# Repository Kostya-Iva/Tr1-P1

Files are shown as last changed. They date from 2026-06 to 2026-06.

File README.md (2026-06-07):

# Tr1-P1
Cartesian parallel manipulator, featuring "Tripteron" with 3 DoF, made as a student project for particular universitu course.
* Image of a robot:

  <p align="center">
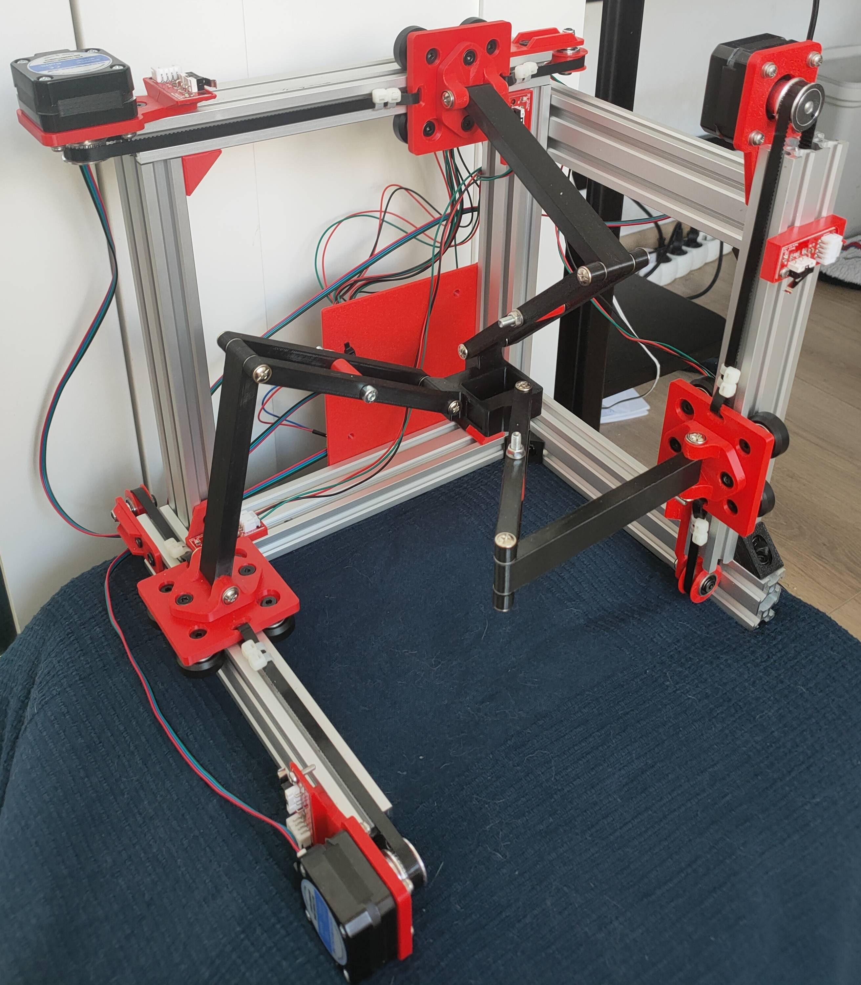
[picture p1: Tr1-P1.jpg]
Trippi
    
  </p>
# Motivation
The Tripteron project was born out of a practical need within the **EPIC** student research group: automating the preparation of metallographic specimens without breaking the bank.

Since professional, dedicated lab equipment is financially out of reach for most student budgets, this project delivers a cost-effective, simple to program, versatile alternative.

# Mechanical design

# Electronical design

# Programming
The system interfaces with three stepper motor drivers (X, Y, Z axes), dedicated limit switches (endstops) for homing, and control hardware.
The code architecture takes form of a state machine and it is described with this diagram:
  <p align="center">
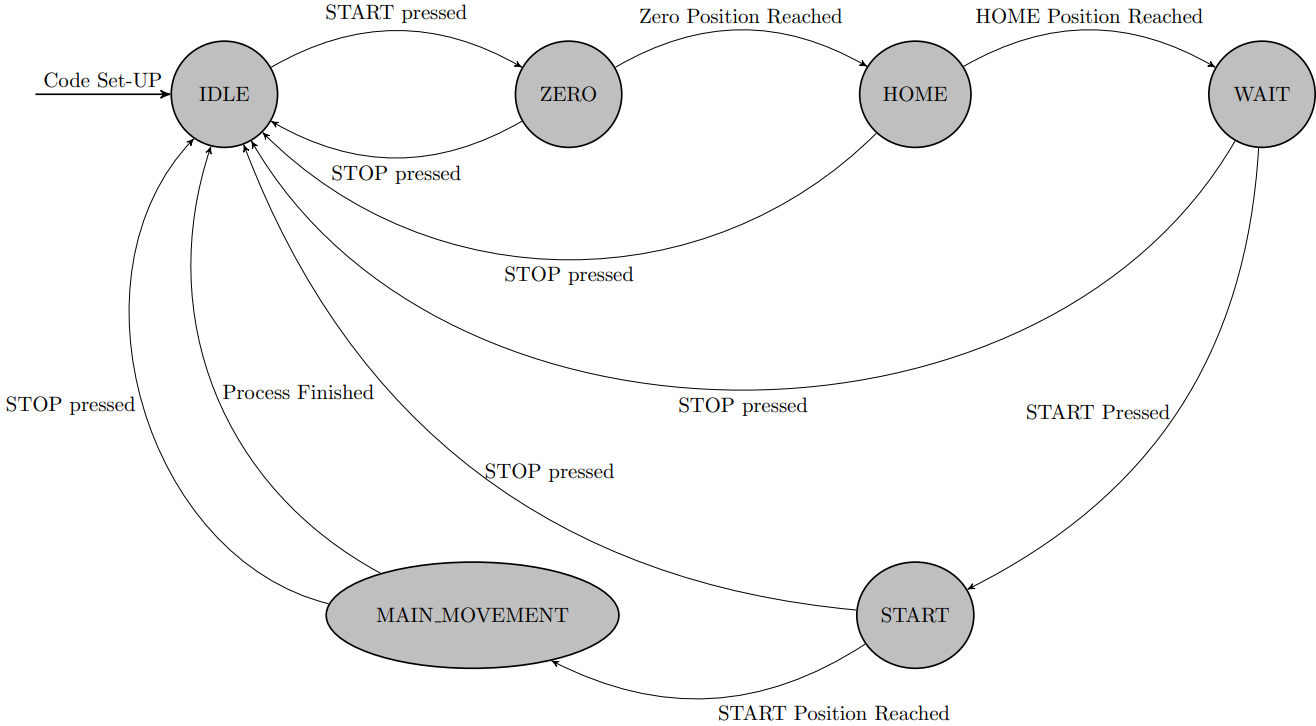
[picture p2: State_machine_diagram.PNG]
Stany
    
  </p>
  
Such architecture is described with one file, named: *stany.ino* written in the Arduino IDE for ESP32 DevBoard 

### Pin Mapping
| Component / Function | ESP32 Pin | Input / Output | Configuration / Description |
| :--- | :---: | :---: | :--- |
| **X-Axis STEP** | `GPIO22` | **OUTPUT** | Generates movement pulses for the X axis |
| **X-Axis DIR** | `GPIO23` | **OUTPUT** | Controls the direction of rotation for the X axis |
| **Y-Axis STEP** | `GPIO18` | **OUTPUT** | Generates movement pulses for the Y axis |
| **Y-Axis DIR** | `GPIO19` | **OUTPUT** | Controls the direction of rotation for the Y axis |
| **Z-Axis STEP** | `GPIO17` | **OUTPUT** | Generates movement pulses for the Z axis |
| **Z-Axis DIR** | `GPIO16` | **OUTPUT** | Controls the direction of rotation for the Z axis |
| **X-Axis Endstop** | `GPIO35` | **INPUT_PULLUP** | Limit switch for X home position |
| **Y-Axis Endstop** | `GPIO32` | **INPUT_PULLUP** | Limit switch for Y home position |
| **Z-Axis-bottom Endstop** | `GPIO33` | **INPUT_PULLUP** | Limit switch for Z home position |
| **Z-Axis-upper Endstop** | `GPIO25` | **INPUT_PULLUP** | Limit switch for Z home position |
| **START Button** | `GPIO14` | **INPUT_PULLUP** | Initiates the calibration and automation cycle |
| **STOP Button** | `GPIO12` | **INPUT_PULLUP** | Hardwired safety trigger for Emergency Stop |
---

#### State Descriptions:

* **`STATE_IDLE`** Remains stationary, actively polling the `START` button pin.
  
* **`STATE_HOMING`** Triggered after pressing START. Establishing the machine's absolute reference point.
  
* **`STATE_READY`** The homing was successfull. The parallel effector is calibrated at its home base, actively polling the `START` button pin.
  
* **`STATE_PROCESSING`** The system dynamically generates step pulses for all three axes simultaneously, executing predefined movement trajectory
  
* **`STATE_FINISHED`** The polishing cycle is complete. Retracts the effector away from the workpiece area, and transitions back to `STATE_IDLE` for the next run.

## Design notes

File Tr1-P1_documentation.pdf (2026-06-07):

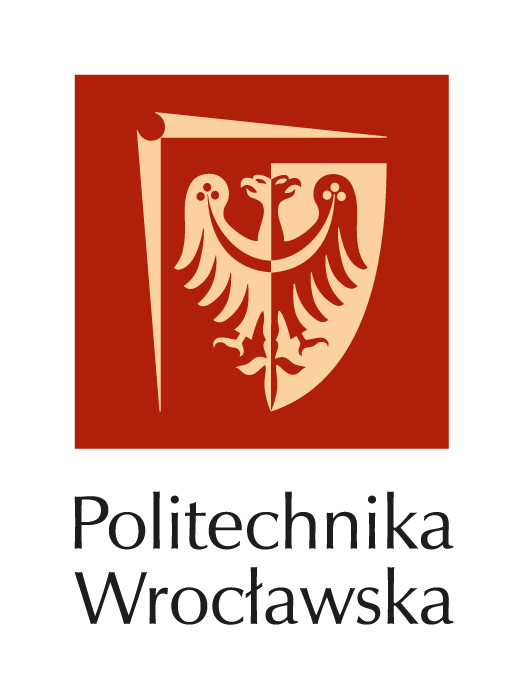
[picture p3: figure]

# Projekt Tripterona

## Bartłomiej Łuczeńczyk 277592 Mikołaj Mroczko 277576 Paweł Czerny 282945 Kostiantyn Ivanov 277567

Projekt Tripterona

## Spis treści

1 Koncept | 3
2 Wymagania | 4
3 Architektura | 5
4 Schemat blokowy architektury | 6
5 Mechanika | 7
6 Elektronika | 12
7 Oprogramowanie | 16
8 Załączniki | 23

## 1 Koncept

Projekt tripterona stanowi alternatywną formę konstrukcji mechanizmu równoległego, który zachowuje równoległość efektora względem płaszczyzny oraz umożliwia niezależny ruch w poszczególnych osiach. Konstrukcja została zaprojektowana z myślą o uniwersalności i łatwej adaptacji do różnych zadań realizowanych przez koło naukowe EPIC.

Platforma ta będzie wykorzystywana do automatyzacji procesu wykonywania zgładów metalograficznych. Ze względu na ograniczony budżet koła naukowego zakup profesjonalnych urządzeń oraz dedykowanych narzędzi nie jest możliwy, dlatego zaproponowane rozwiązanie alternatywne spotkało się z pozytywnym odbiorem zarządu koła.

Aby zminimalizować koszty produkcji urządzenia, podjęto decyzję o wykorzystaniu profili aluminiowych oraz elementów wytwarzanych metodą druku 3D, uzupełnionych o niezbędne komponenty elektroniczne, sensory i aktuatory.

Należy zaznaczyć, że przedstawiona konstrukcja stanowi jedynie prototyp urządzenia. Wersja końcowa może istotnie różnić się pod względem gabarytów, dokładności wykonania oraz zastosowanych materiałów.

Możliwy jest również dalszy rozwój projektu oraz opracowanie nowych, dedykowanych wersji urządzenia, dostosowanych do konkretnych zastosowań.

## 2 Wymagania

Wymagania interesariuszy

- Umożliwia precyzyjne pozycjonowanie efektora w przestrzeni roboczej,
- zapewnia ruch niezależny w trzech osiach (X, Y, Z),
- zachowuje równoległość efektora względem płaszczyzny roboczej,
- rozwiązanie niskokosztowe,
- łatwy w transporcie i adaptacji do różnych zastosowań,

Wymagania systemowe

- Układ ruchu oparty o mechanizm równoległy,
- odpowiedni obszar roboczy (architektura),
- umożliwia sterowanie poprzez mikrokontroler,
- umożliwia integrację odpowiednich końcówek roboczych.

Wymagania funkcjonalne

- przemieszczanie efektora w osiach X, Y, Z,
- utrzymywanie orientacji efektora,
- wykonywanie zaprogramowanej trajektorii ruchu,

Wymagania niefunkcjonalne

- wykorzystanie łatwo dostępnych komponentów,
- łatwość montażu i demontażu, powtarzalności działania urządzenia,
- możliwość przenoszenia urządzenia,

## 3 Architektura

Warstwa mechaniczna
- profile aluminiowe,
- elementy łączące (łączniki kątowe, łączniki systemowe),
- ramiona mechanizmu wykonane metodą druku 3D,
- wózki liniowe,
- prowadnice liniowe,
- platforma efektora,
- koła pasowe, napinacze, taśmy napędowe,
- mocowania silników, obudowy elementów.

Warstwa elektroniczna
- mikrokontroler ESP 32,
- płyta główna,
- sterownik silników krokowych,
- silniki krokowe NEMA 16,
- czujniki krańcowe,
- zasilacz,
- Przyciski start/stop.

Warstwa programowa

- sterowanie silnikami krokowymi,
- obsługa czujników krańcowych,
- procedura homing,
- kontrola trajektorii ruchu,

## 4 Schemat blokowy architektury

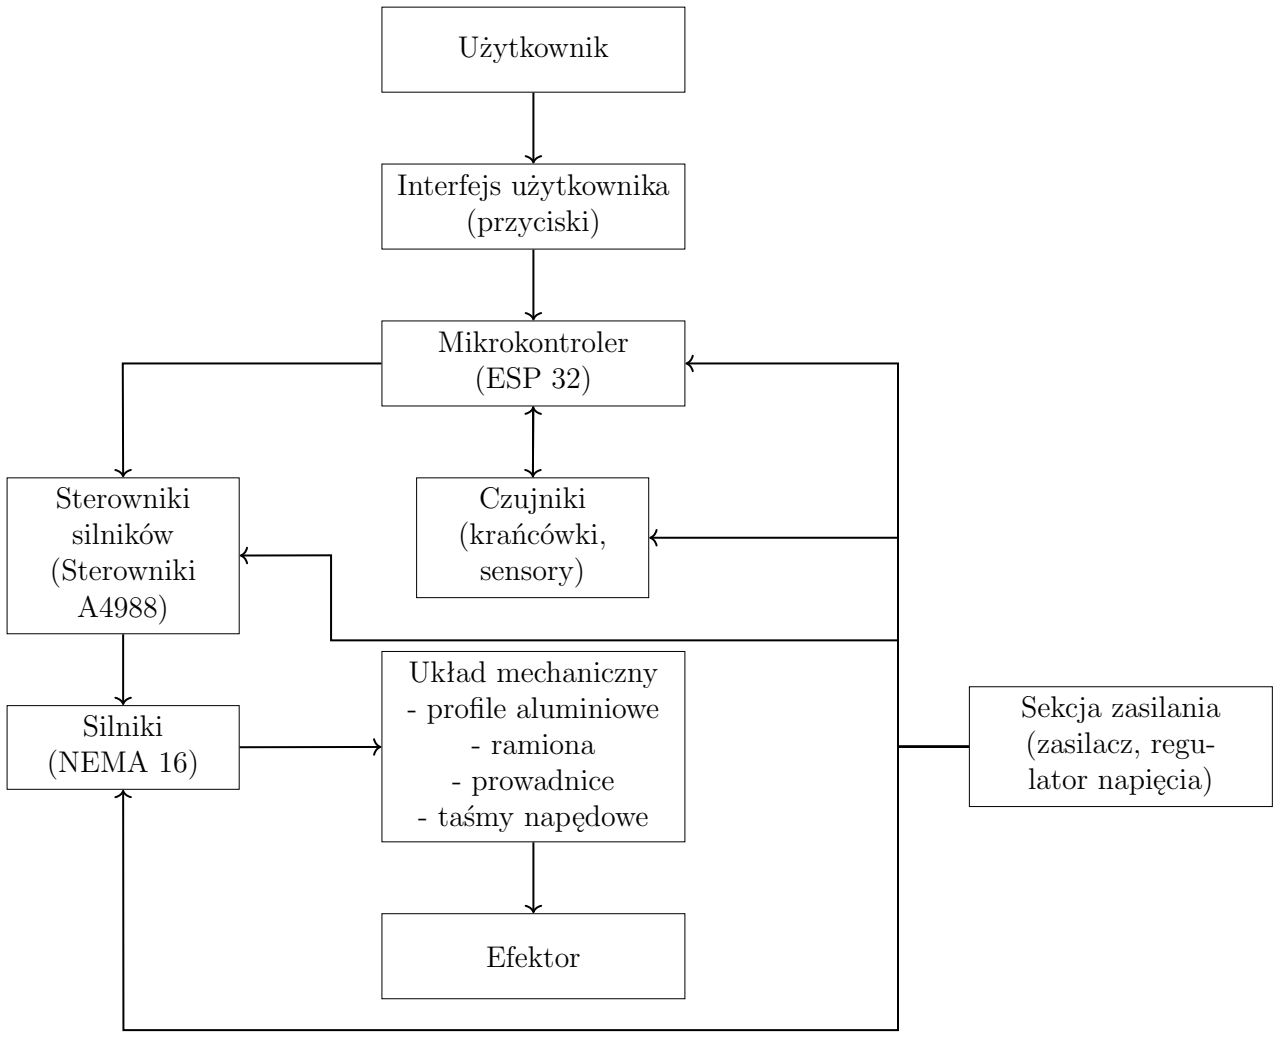
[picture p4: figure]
Użytkownik; Interfejs użytkownika (przyciski); Mikrokontroler (ESP 32); Sterowniki silników (Sterowniki A4988); Silniki (NEMA 16); Czujniki (krańcówki, sensory); Układ mechaniczny - profile aluminiowe - ramiona - prowadnice - taśmy napędowe; Efektor; Sekcja zasilania (zasilacz, regu- lator napięcia)

Rysunek 1: Schemat blokowy architektury systemu tripterona

## 5 Mechanika

### 5.1 Model 3D konstrukcji

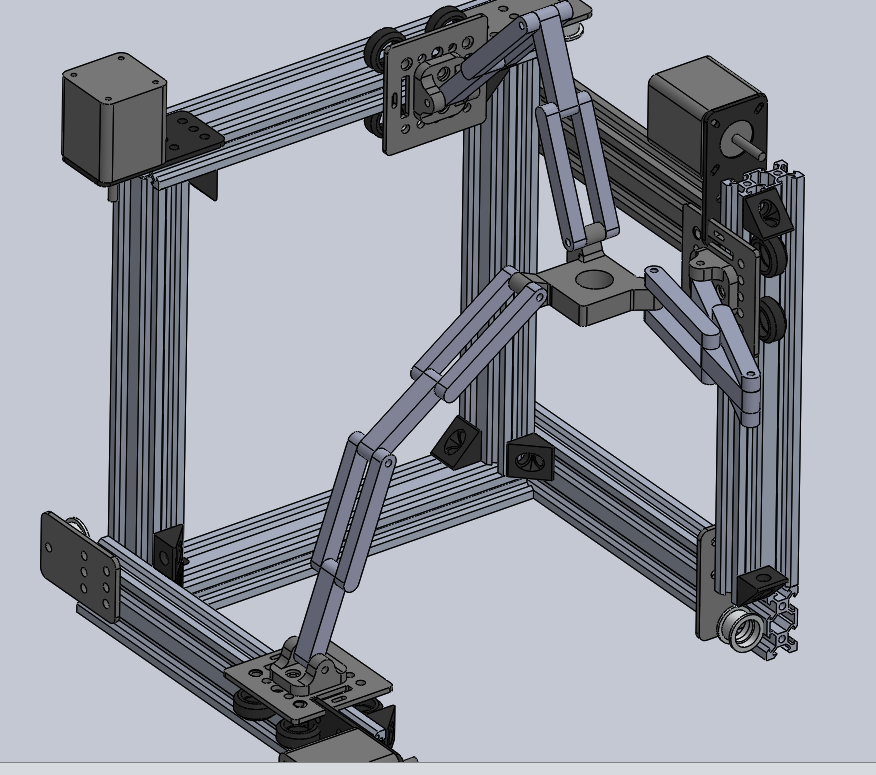
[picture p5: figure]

Rysunek 2: Render modelu 3D zaprojektowanego układu

Rysunek przedstawia finalną geometrię układu po etapach iteracji projektowej. Model stanowi podstawę do analizy mechanicznej i przeprowadzonych symulacji.

Konstrukcja wykonana została ze standardowych profili aluminiowych oraz elementów wykonanych w technice druku 3D. Zastosowanie profili aluminiowych typu V-Slot zapewnia odpowiednią sztywność całej struktury przy jednoczesnym zachowaniu stosunkowo niskiej masy układu oraz umożliwia prowadzenie wózków liniowych. Elementy wykonane w technologii druku 3D znacząco obniżają koszt wykonania oraz pozwalają na dostosowanie części do indywidualnych potrzeb konstrukcji, co umożliwiło szybkie iteracje projektowe oraz optymalizację kształtów pod kątem funkcjonalnym.

### 5.2 Pole robocze

Pole robocze zaprojektowanego układu zostało wyznaczone metodą eksperymentalną poprzez symulację ruchu końcówki efektora z wykorzystaniem przebiegów sinusoidalnych w osiach X, Y oraz Z. Takie podejście pozwoliło na odwzorowanie skrajnych położeń mechanizmu oraz określenie rzeczywistego zakresu pracy układu. Zaprojektowany system posiada pole robocze o wymiarach 12 × 12 × 12 cm, co zapewnia wystarczającą przestrzeń do realizacji zakładanych zadań oraz testów funkcjonalnych. Uzyskany zakres ruchu uwzględnia ograniczenia wynikające z geometrii ramion oraz długości elementów wykonawczych.

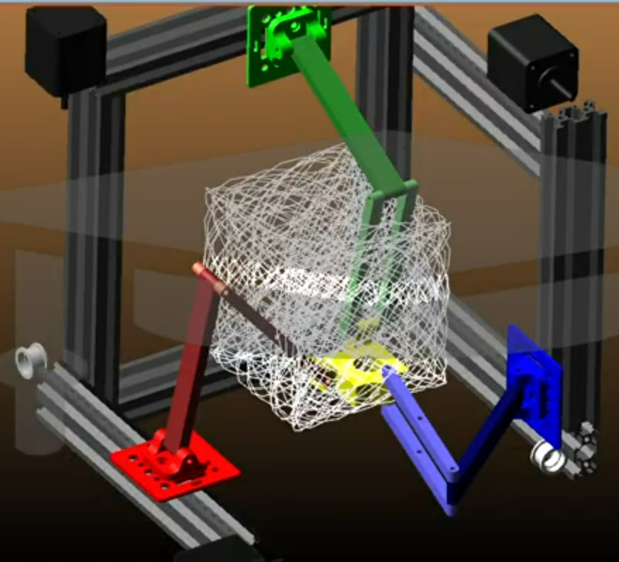
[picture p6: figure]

Rysunek 3: Wizualizacja pola roboczego flanszy efektora

Na rysunku przedstawiono wizualizację wyznaczonego pola roboczego wraz z zaznaczonym obszarem dostępnych pozycji efektora. W praktyce rzeczywisty obszar roboczy może nieznacznie odbiegać od wartości teoretycznych ze względu na luzy mechaniczne oraz elastyczność elementów konstrukcyjnych.

### 5.3 Symulacja

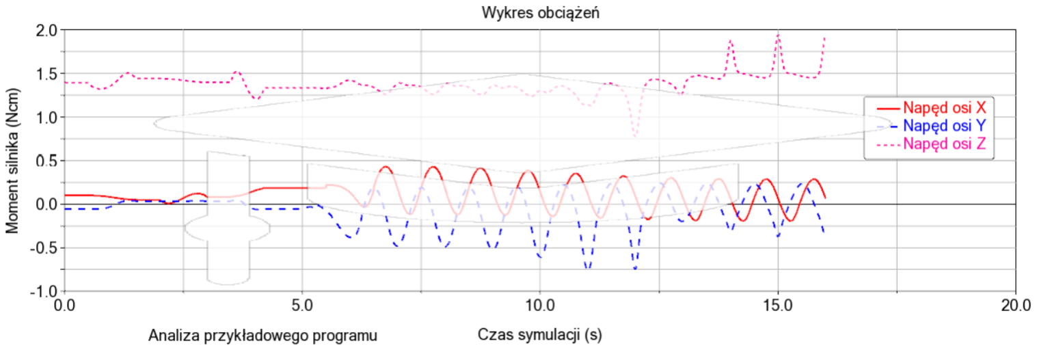
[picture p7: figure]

Rysunek 4: Zarejestrowane siły

Po zamodelowaniu mechanizmu przeprowadzono symulację ruchu w programie Adams w celu wyznaczenia sił działających w poszczególnych osiach układu. Wartości zarejestrowanych sił wynosiły maksymalnie:

- 0,5 Ncm dla osi X
- 0,6 Ncm dla osi Y
- 2,0 Ncm dla osi Z

Warto zaznaczyć, że uzyskane wartości sił mogą ulegać zmianie w zależności od zastosowanego narzędzia roboczego oraz przyjętej trajektorii ruchu manipulatora. Z tego względu przy doborze silników konieczne jest uwzględnienie odpowiedniego zapasu momentu obrotowego. Niewielkie wartości wyznaczonych obciążeń zapewniły jednak dużą swobodę w projektowaniu układu napędowego.

### 5.4 Problemy konstrukcyjne

Jednym z głównych wyzwań projektowych było opracowanie flanszy montażowej efektora. Konstrukcja musiała jednocześnie nie ograniczać pola roboczego urządzenia, zapewniać możliwość łatwego montażu różnych końcówek roboczych oraz umożliwiać integrację serwomechanizmów odpowiedzialnych za sterowanie efektorem. Wymagało to kilku iteracji projektowych.

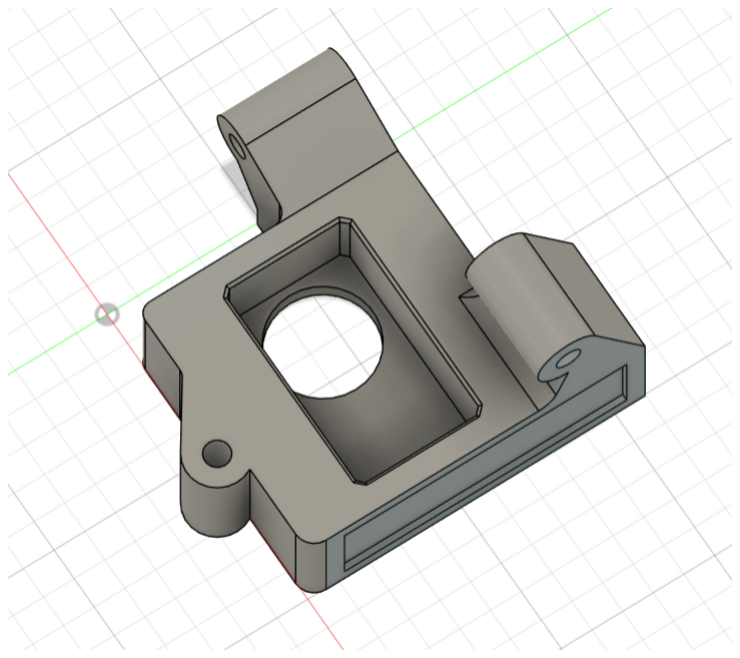
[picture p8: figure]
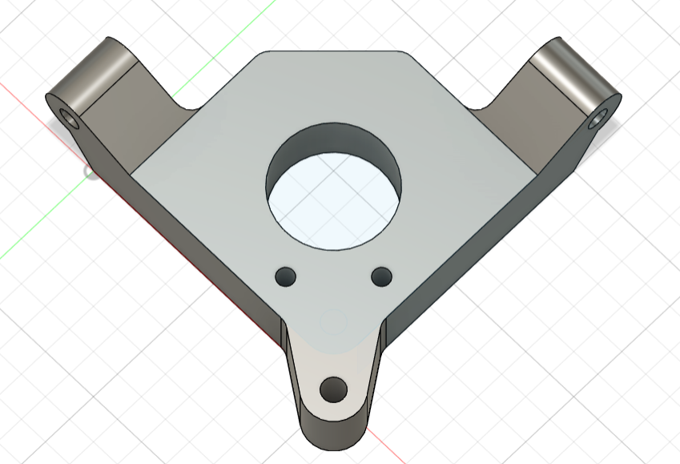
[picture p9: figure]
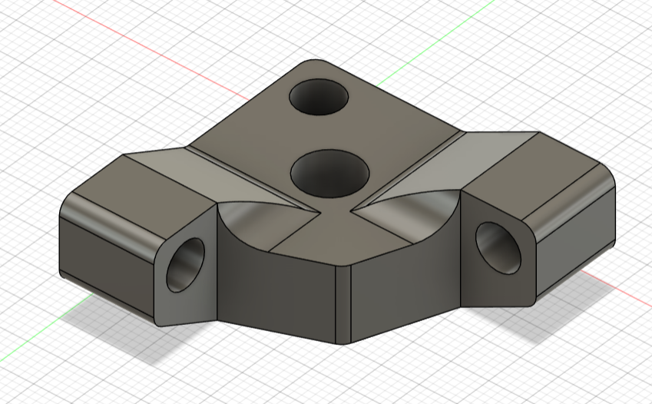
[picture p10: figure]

Rysunek 5: Kolejne wersje projektu flanszy efektora

Końcowa wersja pozwoliła uzyskać maksymalny obszar roboczy zostawiając pole na montaż zarówno efektorów jak i przykręcenie serwomechanizmów.
Kolejnym istotnym problemem projektowym była konstrukcja ramion robota. Głównym celem było zminimalizowanie masy całego układu przy jednoczesnym zachowaniu odpowiedniej sztywności konstrukcji. Dodatkowym wyzwaniem było takie zaprojektowanie geometrii ramion, aby uniknąć ich wzajemnego krzyżowania się w pełnym zakresie ruchu.

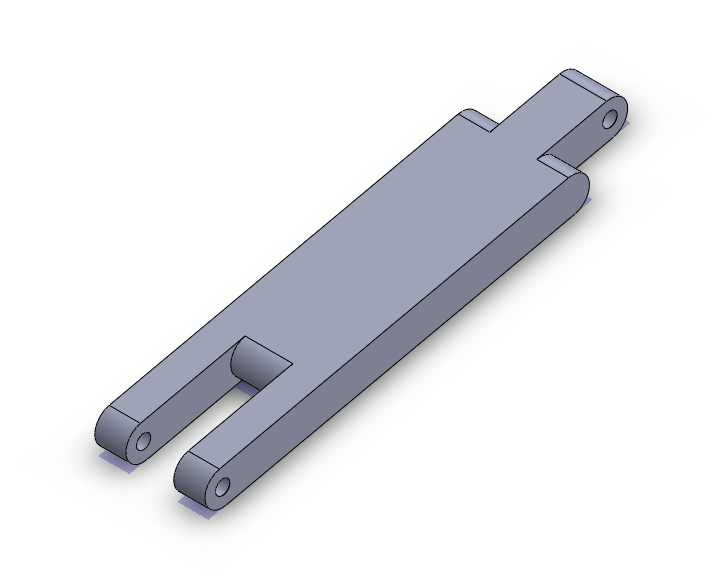
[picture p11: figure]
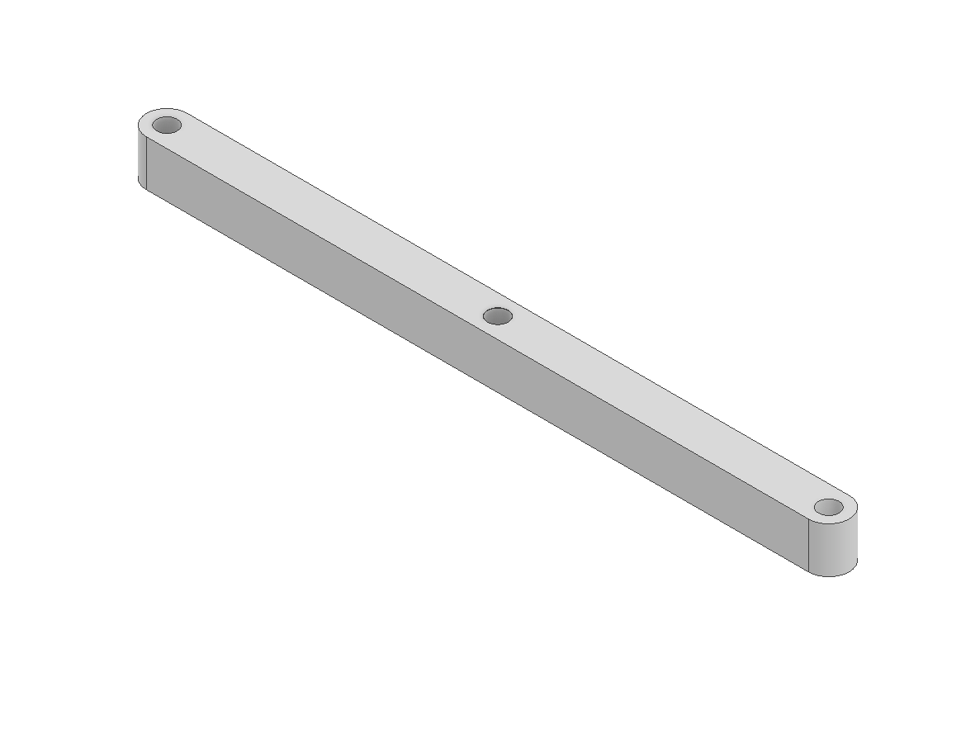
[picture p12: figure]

Rysunek 6: Kolejne wersje projektu ramion robota

### 5.5 Interfejs mechanika–elektronika

Na podstawie wykonanej konstrukcji oraz przeprowadzonych symulacji dobrano silniki napędowe typu Nema 16 Bipolar o momencie trzymającym 12 Ncm oraz kącie kroku 0,9°. Zastosowane silniki zapewniają odpowiedni zapas momentu względem obciążeń wynikających z masy elementów ruchomych oraz oporów mechanicznych układu. Wybór silników o mniejszym kącie kroku umożliwia realizację ruchów o wysokiej rozdzielczości, co bezpośrednio przekłada się na precyzję pozycjonowania osi roboczych.

Przyjęta konstrukcja mechaniczna pozwoliła również na określenie wymagań dla układu elektronicznego odpowiedzialnego za sterowanie ruchem. Liczba osi roboczych oraz zastosowane silniki krokowe determinują konieczność zastosowania wielokanałowego systemu sterowania umożliwiającego niezależną kontrolę każdej osi.

Ze względu na charakterystykę zastosowanych silników wymagane jest sterowanie mikrokrokowe, które zwiększa efektywną rozdzielczość ruchu oraz ogranicza drgania układu mechanicznego. Układ sterowania powinien zapewniać odpowiedni prąd fazowy, a także umożliwiać płynną regulację prędkości i przyspieszeń, co pozwala na uniknięcie gubienia kroków podczas pracy dynamicznej.

### 5.6 Spis elementów konstrukcyjnych

Lp. | Nazwa elementu | Kod / oznaczenie | Ilość
1 | Śruba Low Profile M5x25mm | M5x25mm | 12
2 | Śruba Low Profile M5x8mm | M5x8mm | 12
3 | Dystans aluminiowy 6mm | HW1018NC | 6
4 | Dystans aluminiowy 3mm | HW1016NC | 3
5 | Double T-NUT M5 | HW1029NC | 6
6 | T-nut | - | 3
7 | Zębatka GT2 (30 zębów, otw. Fi.5) | HW1036WC | 3
8 | Kółka (Xtreme Solid lub Solid) | HW1215WK / HW1212WK | 12
9 | Idler Pulley | HW1093WK | 3
10 | Napiacz | Druk własny | 3
11 | Podkładka do silnika (DYNAMIXEL) | Druk własny | 3
12 | Podkładka do silnika (NEMA) | Druk własny | 3
13 | Płyta V-SLOT Gantry Plate (Opcja 20mm) | Druk własny | 3
14 | Pasek GT2 5mm | HW1037GC | 3
15 | Profil V-SLOT 2040 | 2040-sr-mb | 8
16 | Silnik krokowy NEMA 16 Bipolar | 16HM12-0634D | 3
17 | Eccentric Spacer 6mm | HW1073NC | 6
18 | Zacisk do pasków zębatych | HW1024GC | 3
19 | Złącze meblowe śrubowe | - | 3
20 | Ramię | Druk własny | 3
21 | Przedramię | Druk własny | 6
22 | Kiść | Druk własny | 1
23 | Bark | Druk własny | 3
24 | Łączniki profili | Druk własny | 10

Tabela 1: Zestawienie elementów konstrukcyjnych

## 6 Elektronika

### 6.1 Schemat ideowy

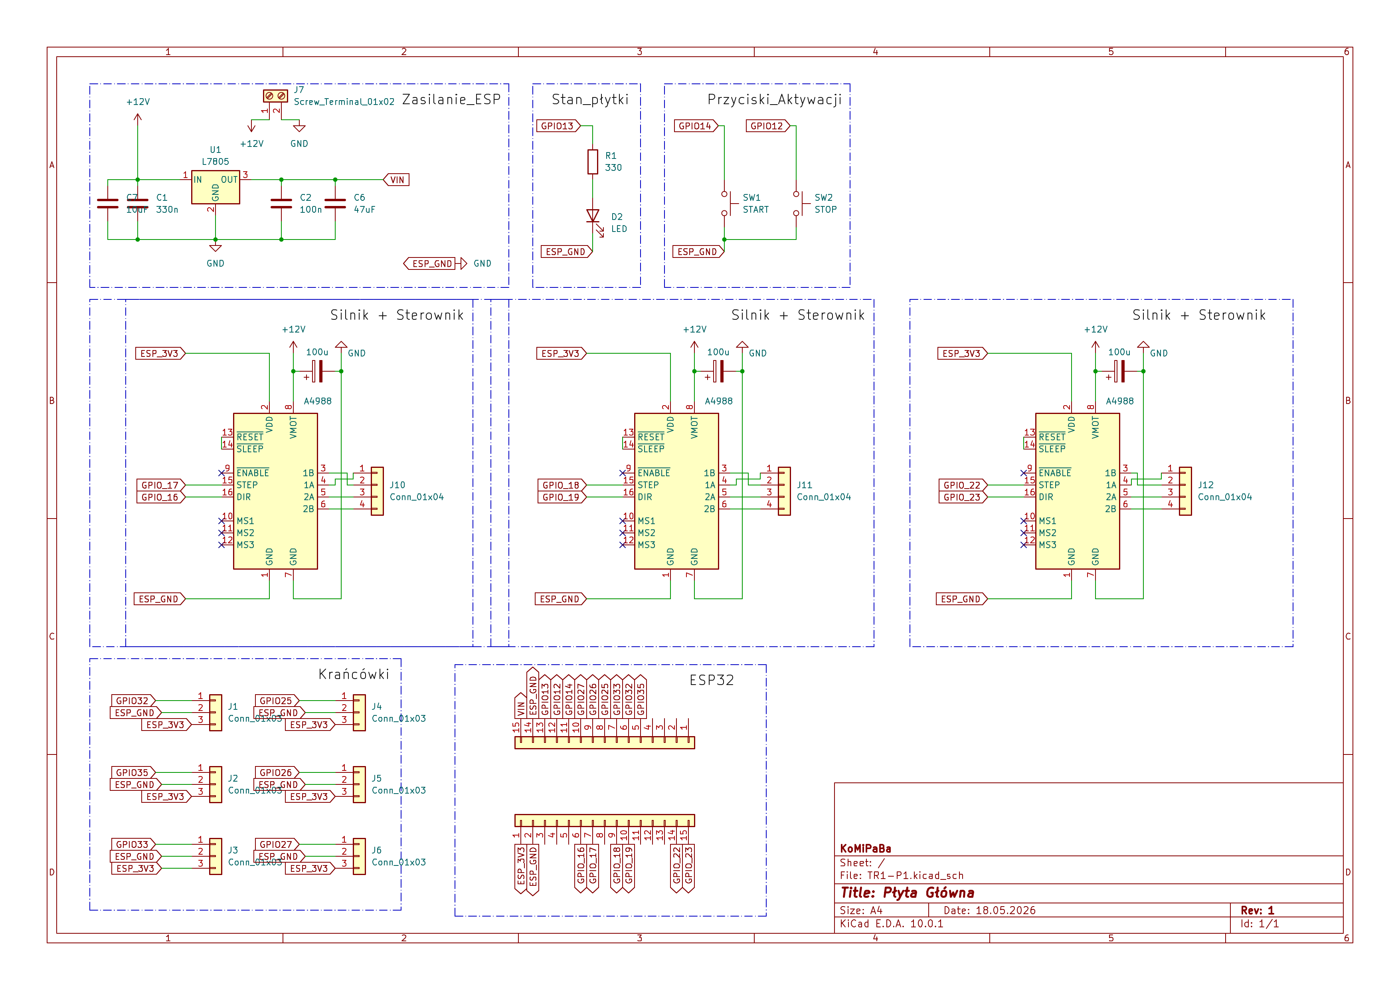
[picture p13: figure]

Rysunek 7: Schemat ideowy płyty głównej

### 6.2 Model płytki

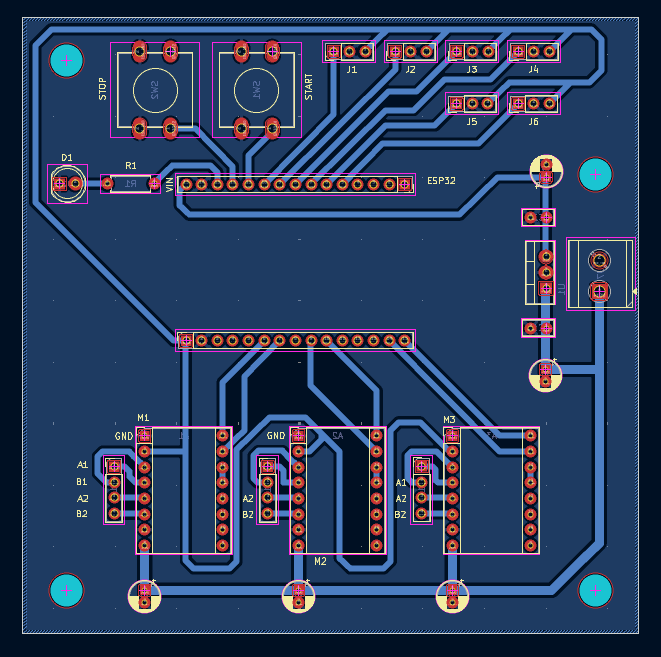
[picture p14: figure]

Rysunek 8: Schenat połączeń

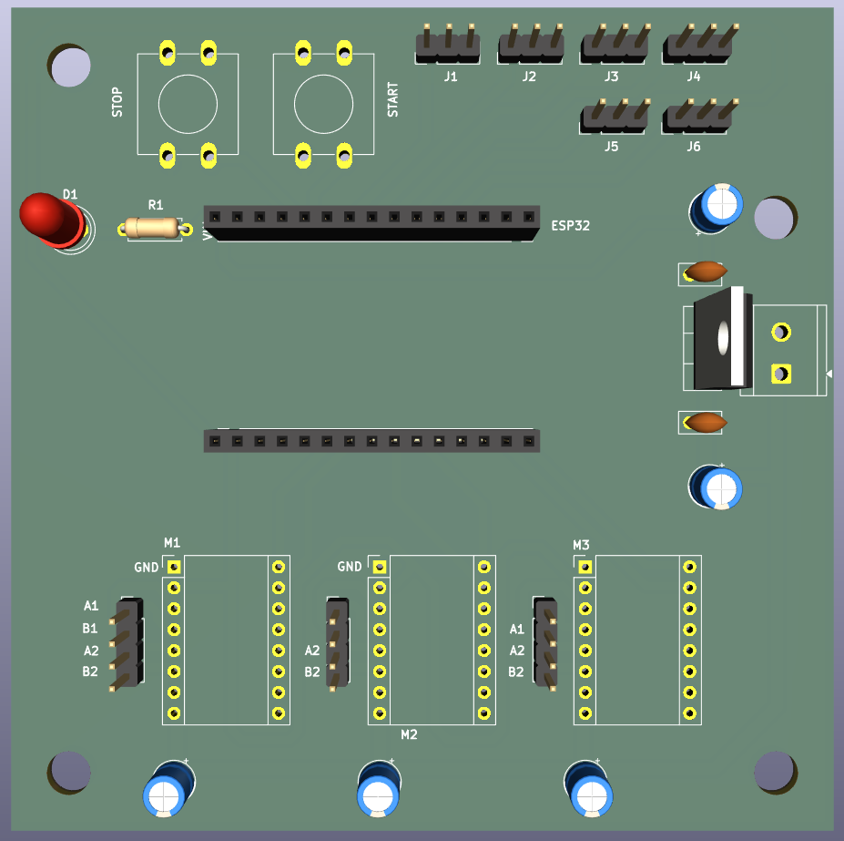
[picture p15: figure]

Rysunek 9: Model 3D płytki

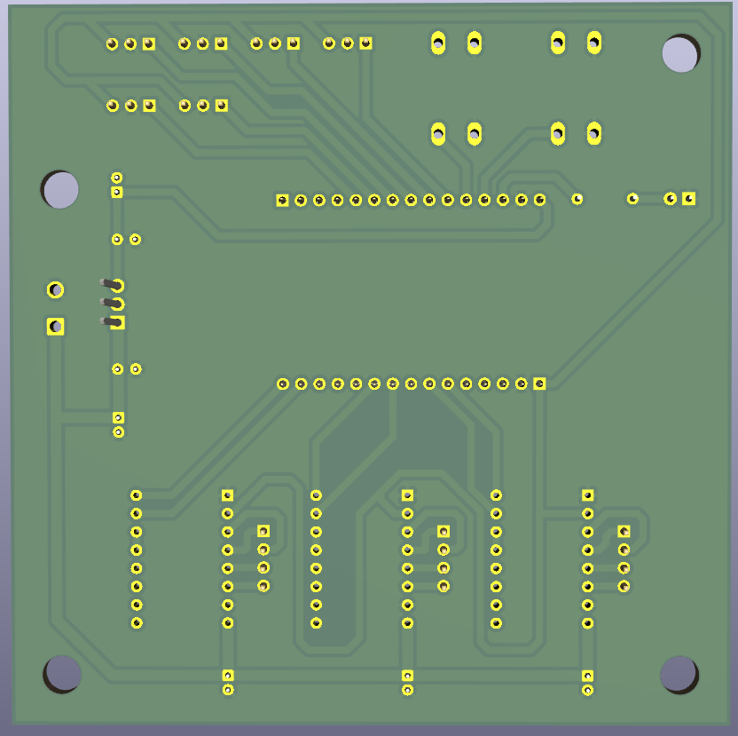
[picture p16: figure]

Rysunek 10: Model 3D płytki

### 6.3 Zastosowane moduły

Układ sterowania został oparty o mikrokontroler ESP32-WROOM, pełniący rolę jednostki nadrzędnej systemu. Mikrokontroler odpowiada za generowanie sygnałów sterujących dla sterowników silników krokowych, obsługę krańcówek oraz komunikację z użytkownikiem.

Do sterowania napędami zastosowano trzy moduły A4988, umożliwiające sterowanie bipolarnymi silnikami krokowymi w trybie pełnego kroku, półkroku oraz mikrokroku. Sterowniki realizują kontrolę kierunku obrotów (DIR) oraz liczby wykonywanych kroków (STEP).

System wyposażono w sześć krańcówek mechanicznych kompatybilnych z systemem sterowania. Ich zadaniem jest wyznaczanie pozycji zerowych manipulatora oraz zabezpieczenie układu przed przekroczeniem dopuszczalnego zakresu ruchu.

Na płytce przewidziano również diodę LED sygnalizującą stan zasilania oraz przyciski umożliwiające reset lub uruchomienie trybu pracy mikrokontrolera.

### 6.4 Zasilanie

Układ zasilany jest z zewnętrznego zasilacza sieciowego o napięciu 12 (lub 9) V DC, podłączanego do złącza śrubowego na płytce głównej.

Napięcie 12 V wykorzystywane jest bezpośrednio do zasilania sterowników silników krokowych A4988, które następnie dostarczają odpowiednią energię do silników krokowych.

Dla części logicznej układu zastosowano stabilizator liniowy LM7805, który obniża napięcie wejściowe 12 V do poziomu 5 V. Napięcie to jest podawane na pin VIN mikrokontrolera ESP32, gdzie następnie jest ono dalej przetwarzane przez wewnętrzny stabilizator na napięcie 3,3 V wymagane do pracy rdzenia mikrokontrolera.

Zastosowanie kondensatorów filtrujących pozwala na stabilizację napięcia oraz redukcję zakłóceń powstających podczas pracy silników krokowych, które generują dynamiczne zmiany obciążenia zasilania.

### 6.5 Spis elementów elektronicznych

Lp. | Nazwa elementu | Kod / oznaczenie | Ilość
1 | Moduł mikrokontrolera ESP32 WROOM | ESP32-WROOM | 1
2 | Sterownik silnika krokowego | A4988 | 3
3 | Złącze GoldPIN 1x15 | 1x15 | 2
4 | Złącze GoldPIN 1x8 | 1x8 | 6
5 | Złącze GoldPIN 1x3 | 1x3 | 6
6 | Złącze GoldPIN 1x4 | 1x4 | 3
7 | Przycisk THT 12x12 mm | 12x12 | 2
8 | Dioda LED | LED | 1
9 | Kondensator ceramiczny 100 nF | 100nF | 2
10 | Kondensator elektrolityczny 100 µF | 100uF | 3
11 | Kondensator elektrolityczny 10 µF | 10uF | 1
12 | Kondensator elektrolityczny 47 µF | 47uF | 1
13 | Stabilizator napięcia | LM7805 | 1
14 | Złącze śrubowe 1x2 | 1x2 | 1
15 | Rezystor 330 Ω | 330R | 1
16 | Krańcówka mechaniczna (RAMPS 1.4) | Endstop / Limit Switch | 6

Tabela 2: Zestawienie elementów elektronicznych

## 7 Oprogramowanie

### 7.1 Architektura sterowania

W programie zastosowano mechanizm maszyny stanów, który odpowiada za organizację pracy całego układu. Sterowanie zostało podzielone na zestaw jasno zdefiniowanych stanów odpowiadających kolejnym etapom działania mechanizmu, takim jak: oczekiwanie na uruchomienie, procedura bazowania, przejazd do pozycji startowej, oczekiwanie na rozpoczęcie procesu oraz realizacja ruchu roboczego.

Każdy stan posiada własną logikę działania oraz warunki przejścia do kolejnego etapu pracy. Takie rozwiązanie upraszcza zarządzanie algorytmem sterowania, poprawia czytelność kodu oraz ułatwia rozbudowę i diagnostykę systemu.

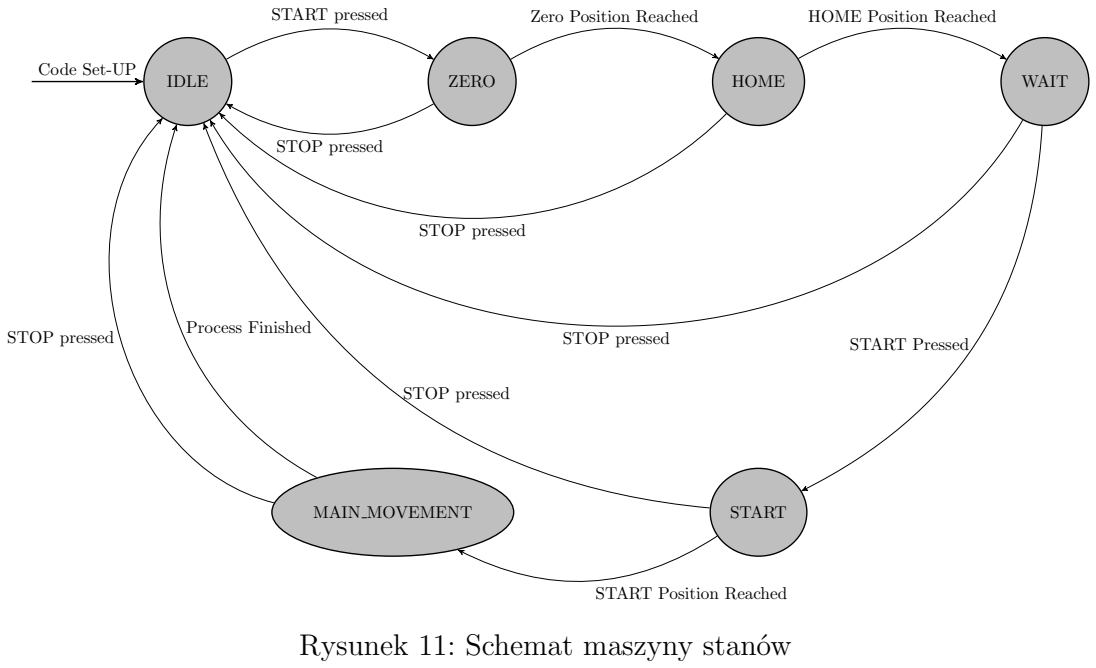
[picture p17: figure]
IDLE; Code Set-UP; ZERO; HOME; WAIT; MAIN MOVEMENT; START; START pressed; STOP pressed; Zero Position Reached; HOME Position Reached; START Pressed; START Position Reached; Process Finished STOP pressed; Rysunek 11: Schemat maszyny stanów

### 7.2 Konfiguracja sprzętowa układu

Tabela 3: Konfiguracja sterowania silnikami krokowymi

Oś | STEP | DIR
X | GPIO22 | GPIO23
Y | GPIO18 | GPIO19
Z | GPIO17 | GPIO16

Tabela 4: Konfiguracja krańcówek

Krańcówka | Pin | Funkcja
kran x | GPIO35 | Wyznaczanie pozycji zerowej osi X
kran y | GPIO32 | Wyznaczanie pozycji zerowej osi Y
kran z 1 | GPIO33 | Dolna krańcówka osi Z
kran z 2 | GPIO25 | Górna krańcówka osi Z

Tabela 5: Konfiguracja przycisków sterujących

Przycisk | Pin | Funkcja
START | GPIO14 | Rozpoczęcie procedury bazowania lub uruchomienie procesu roboczego
STOP | GPIO12 | Natychmiastowe zatrzymanie progra-mu i przejście do stanu IDLE

Tabela 6: Zachowanie diody LED w poszczególnych stanach programu

Stan programu | Zachowanie diody LED
STATE IDLE | Dioda świeci światłem ciągłym (stan wyso-ki).
STATE ZERO | Dioda pozostaje wyłączona po rozpoczęciu procedury bazowania.
STATE HOME | Dioda zachowuje poprzedni stan (wyłączo-na).
STATE WAIT | Dioda miga z okresem 1000 ms, sygnalizu-jąc gotowość układu.
STATE START | Dioda wykonuje trzykrotne mignięcie pod-czas uruchamiania procesu.
STATE MAIN MOVEMENT | Dioda wyłączona podczas wykonywania ruchu roboczego.

### 7.3 Procedura Homing

Fragment kodu przedstawia implementację procedury Homing zrealizowanej w stanie STATE ZERO. Bazowanie wykonywane jest sekwencyjnie dla osi X, Y oraz Z. Każda oś porusza się do momentu aktywacji odpowiedniej krańcówki, po czym jej aktualna pozycja zostaje ustawiona jako pozycja zerowa przy pomocy funkcji setCurrentPosition(0). Po zakończeniu bazowania wszystkich osi program przechodzi do procedury ustawiania pozycji startowej (STATE HOME).

case STATE_ZERO :

if (! is_X_true ) {
if ( value_x == LOW ) {
stepper1 . setCurrentPosition (0) ; is_X_true = true ;
} else {
stepper1 . runSpeed () ;

}

}

if (! is_Y_true ) {
if ( value_y == LOW ) {
stepper2 . setCurrentPosition (0) ; is_Y_true = true ;
} else if ( is_X_true ) {
stepper2 . runSpeed () ;

}

}

if (! is_Z_true ) {
if ( value_z_1 == LOW ) {
stepper3 . setCurrentPosition (0) ; is_Z_true = true ;
} else if ( is_Y_true && is_X_true ) { stepper3 . runSpeed () ;

}

}

if ( is_X_true && is_Y_true && is_Z_true ) { stepper1 . moveTo ( -150) ;
stepper2 . moveTo ( -200) ;
currentState = STATE_HOME ;

}
break ;

Tabela 7: Przebieg procedury Homing

Etap | Opis działania
1 | Ruch osi X do krańcówki zerowej.
2 | Wyzerowanie pozycji osi X.
3 | Ruch osi Y do krańcówki zerowej.
4 | Wyzerowanie pozycji osi Y.
5 | Ruch osi Z do dolnej krańcówki.
6 | Wyzerowanie pozycji osi Z.
7 | Przejście do ustawiania pozycji startowej HOME.

### 7.4 Trajektoria robocza

Trajektoria robocza realizowana jest poprzez ciągłą zmianę prędkości osi X oraz Y w funkcji czasu. Algorytm wykorzystuje zależności trygonometryczne funkcji sinus i cosinus, co pozwala uzyskać ruch po trajektorii kołowej.

Prędkości chwilowe osi wyznaczane są według zależności:

Vx = −Vmax sin(θ)

Vy = Vmax cos(θ)

gdzie:

- Vx – chwilowa prędkość osi X,
- Vy – chwilowa prędkość osi Y,
- Vmax – maksymalna prędkość ruchu,
- θ – aktualny kąt ruchu wyznaczany na podstawie czasu trwania cyklu.

Zastosowanie sterowania prędkościowego pozwala na płynne odwzorowanie ruchu kołowego bez konieczności definiowania dyskretnych punktów trajektorii.

Tabela 8: Parametry trajektorii roboczej

Parametr | Wartość | Opis
predkosc x | 150 | Maksymalna prędkość osi X [kroki/s]
predkosc y | 150 | Maksymalna prędkość osi Y [kroki/s]
kroki x | 100 | Promień trajektorii w osi X [kroki]
kroki y | 100 | Promień trajektorii w osi Y [kroki]
minuty | 1 | Czas realizacji procesu [min]
wymagana liczba | wyliczana | Liczba pełnych cykli trajektorii robo-czej
1 | float obwod_kroki = 2.0 * PI * kroki_x ;
2 | unsigned long czas_okregu_ms =
3 | ( obwod_kroki / predkosc_x ) * 1000;

4
5 for ( int cykl = 0; cykl < wymagana_liczba ; cykl ++) {

6
7 | unsigned long start_cyklu = millis () ;
8 | unsigned long czas_aktualny = millis () ;

9
10 | while ( czas_aktualny - start_cyklu < czas_okregu_ms ) {

11
12 | czas_aktualny = millis () ;

13
14 | float progres =
15 | ( float ) ( czas_aktualny - start_cyklu )
16 | / czas_okregu_ms ;

17
18 | float kat = progres * 2.0 * PI ;

19
20 | float aktualna_predkosc_x =
21 | - predkosc_x * sin( kat ) ;

22
23 | float aktualna_predkosc_y =
24 | predkosc_y * cos( kat ) ;

25
26 | stepper1 . setSpeed ( aktualna_predkosc_x ) ;
27 | stepper2 . setSpeed ( aktualna_predkosc_y ) ;

28
29 | stepper1 . runSpeed () ;
30 | stepper2 . runSpeed () ;
31 | }
32 | }

### 7.5 Dodatkowe funkcje programu

### 7.5.1 Definicja maszyny stanów

Sterowanie programem zrealizowano przy pomocy maszyny stanów FSM. Każdy stan odpowiada za określony etap pracy układu.

1 | enum State {
2 | STATE_IDLE ,
3 | STATE_ZERO ,
4 | STATE_HOME ,
5 | STATE_WAIT ,
6 | STATE_START ,
7 | STATE_MAIN_MOVEMENT
8 | };

9
10 State currentState = STATE_IDLE ;

### 7.5.2 Logika START

Naciśnięcie przycisku START inicjuje procedurę bazowania poprzez wyzerowanie flag stanu oraz przejście do stanu STATE ZERO.

1 case STATE_IDLE :

2
3 if ( digitalRead ( STARTbutton ) == LOW ) {

4
5 | is_X_true = false ;
6 | is_Y_true = false ;
7 | is_Z_true = false ;

8
9 | stepper1 . setSpeed (200) ;
10 | stepper2 . setSpeed (200) ;
11 | stepper3 . setSpeed ( -30) ;

12
13 | currentState = STATE_ZERO ;
14 | }

15
16 break ;

### 7.5.3 Pozycja startowa

Po zakończeniu bazowania mechanizm przejeżdża do zadanej pozycji roboczej HO-ME.

1 | stepper1 . moveTo ( -150) ;
2 | stepper2 . moveTo ( -200) ;

3
4 | while ( stepper1 . distanceToGo () != 0 ||
5 | stepper2 . distanceToGo () != 0) {

6
7 | stepper1 . run () ;
8 | stepper2 . run () ;
9 | }

10
11 | stepper1 . setCurrentPosition (0) ;
12 | stepper2 . setCurrentPosition (0) ;

### 7.5.4 Obsługa STOP

Przycisk STOP monitorowany jest w każdym stanie pracy programu. Jego aktywacja powoduje natychmiastowe przejście do stanu spoczynkowego.

1 | if ( digitalRead ( STOPbutton ) == LOW )
2 | currentState = STATE_IDLE ;

## 8 Załączniki

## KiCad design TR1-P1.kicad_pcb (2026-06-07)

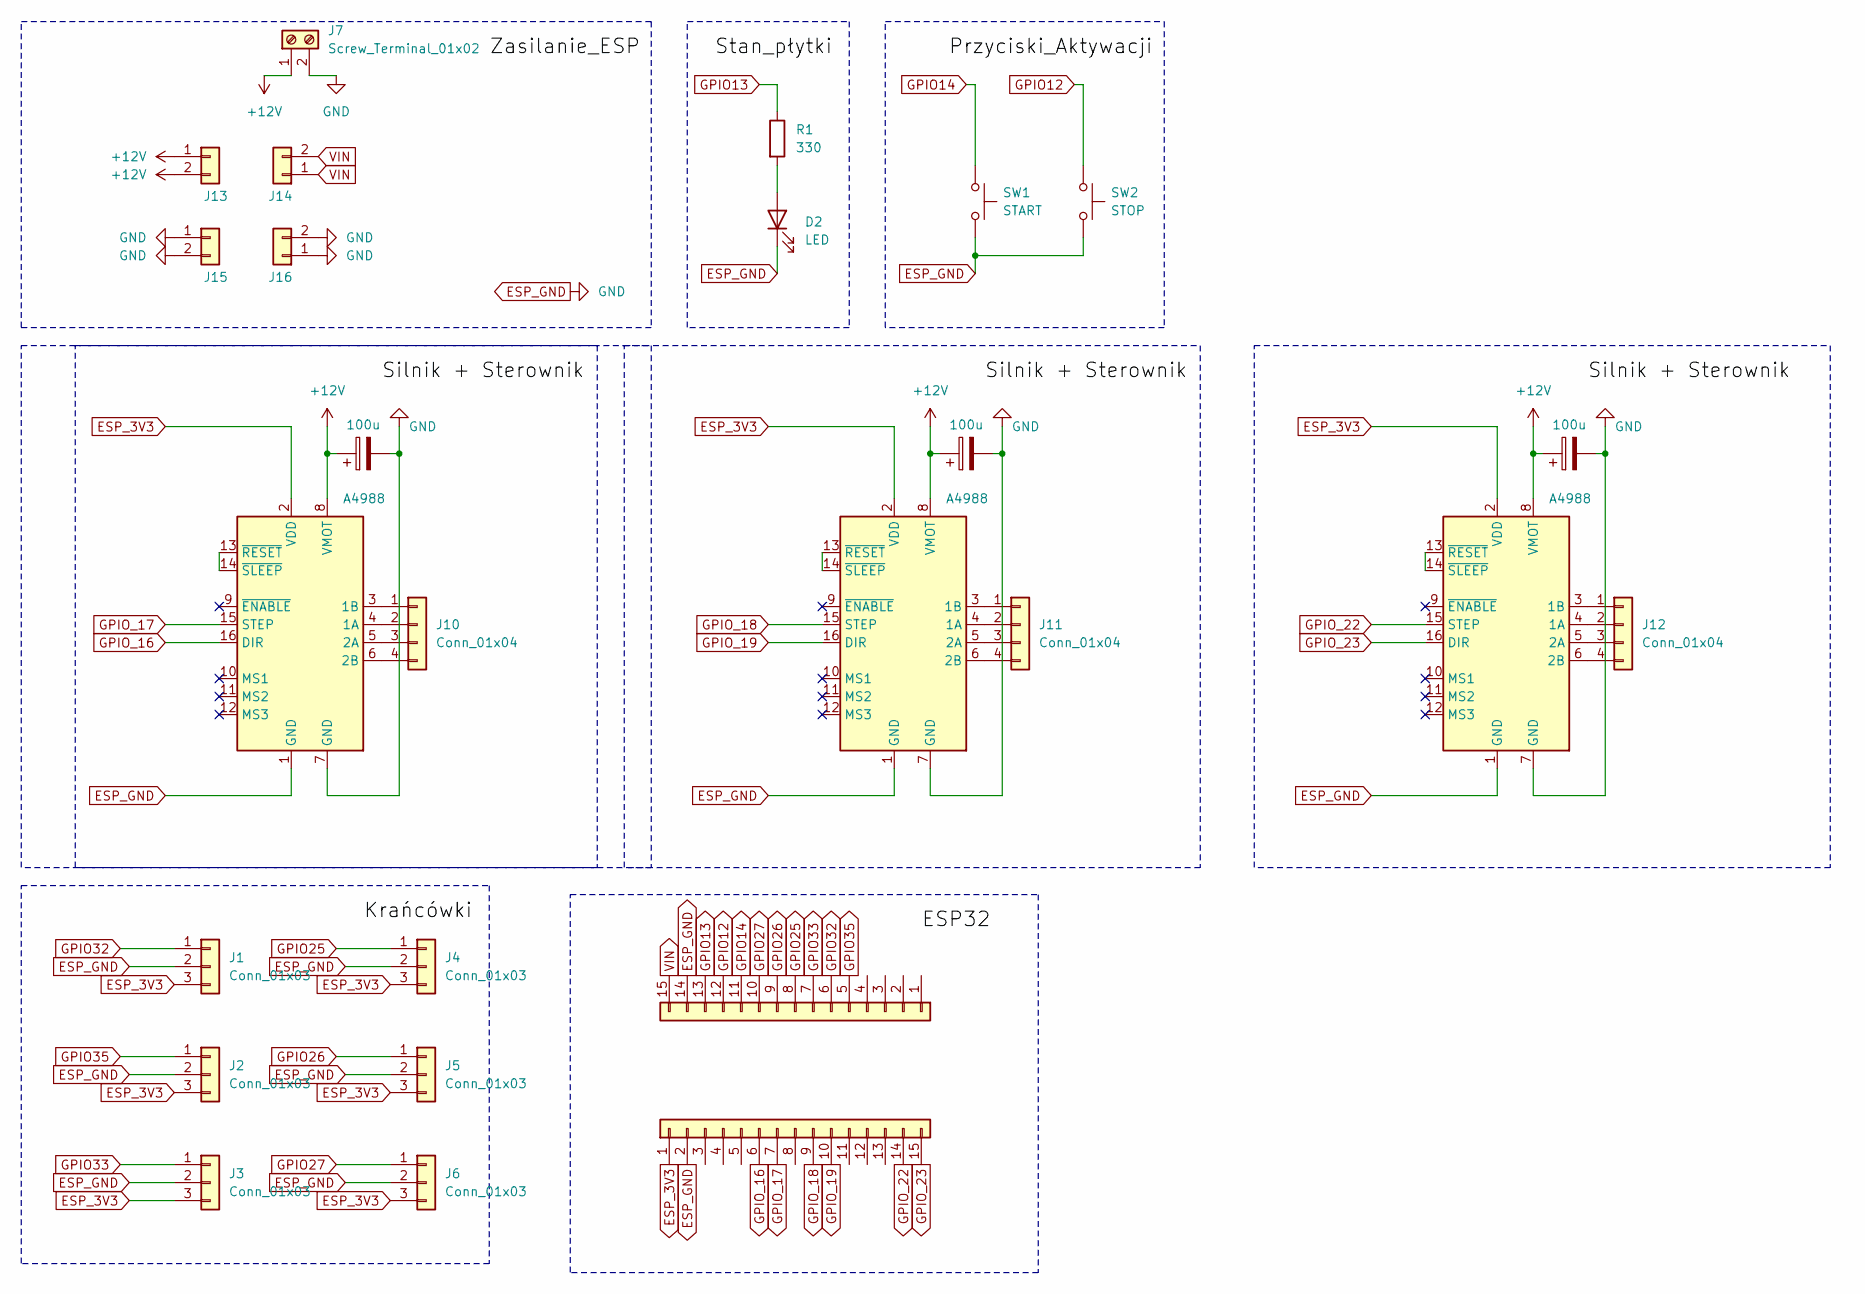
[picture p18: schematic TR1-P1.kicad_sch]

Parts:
A1, A2, A3: A4988; Pololu_Breakout-16_15.2x20.3mm
C3, C4, C5: 100u; CP_Radial_D5.0mm_P2.00mm
D2: LED; LED_D5.0mm
J1, J2, J3, J4, J5, J6: Conn_01x03; PinHeader_1x03_P2.54mm_Vertical
J7: Screw_Terminal_01x02; TerminalBlock_CUI_TB007-508-02_1x02_P5.08mm_Horizontal
J8, J9: Conn_01x15; PinSocket_1x15_P2.54mm_Vertical
J10, J11, J12: Conn_01x04; PinHeader_1x04_P2.54mm_Vertical
J13, J14, J15, J16: Conn_01x02; PinSocket_1x02_P2.54mm_Vertical
R1: 330; R_Axial_DIN0207_L6.3mm_D2.5mm_P7.62mm_Horizontal
SW1: START; SW_PUSH-12mm
SW2: STOP; SW_PUSH-12mm

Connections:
+12V: A1.8 (VMOT), A2.8 (VMOT), A3.8 (VMOT), C3.1, C4.1, C5.1, J7.1, J13.1, J13.2
ESP_3V3: A1.2 (VDD), A2.2 (VDD), A3.2 (VDD), J1.3, J2.3, J3.3, J4.3, J5.3, J6.3, J8.1
ESP_GND: A1.1 (GND), A1.7 (GND), A2.1 (GND), A2.7 (GND), A3.1 (GND), A3.7 (GND), C3.2, C4.2, C5.2, D2.1 (K), J1.2, J2.2, J3.2, J4.2, J5.2, J6.2, J7.2, J8.2, J9.14, J15.1, J15.2, J16.1, J16.2, SW1.2, SW2.2
GPIO12: J9.12, SW2.1
GPIO13: J9.13, R1.1
GPIO14: J9.11, SW1.1
GPIO25: J4.1, J9.8
GPIO26: J5.1, J9.9
GPIO27: J6.1, J9.10
GPIO32: J1.1, J9.6
GPIO33: J3.1, J9.7
GPIO35: J2.1, J9.5
GPIO_16: A1.16 (DIR), J8.6
GPIO_17: A1.15 (STEP), J8.7
GPIO_18: A2.15 (STEP), J8.9
GPIO_19: A2.16 (DIR), J8.10
GPIO_22: A3.15 (STEP), J8.14
GPIO_23: A3.16 (DIR), J8.15
unnamed: A1.4 (1A), J10.2
unnamed: A1.3 (1B), J10.1
unnamed: A1.5 (2A), J10.3
unnamed: A1.6 (2B), J10.4
unnamed: A1.13 (~RESET), A1.14 (~SLEEP)
unnamed: A2.4 (1A), J11.2
unnamed: A2.3 (1B), J11.1
unnamed: A2.5 (2A), J11.3
unnamed: A2.6 (2B), J11.4
unnamed: A2.13 (~RESET), A2.14 (~SLEEP)
unnamed: A3.4 (1A), J12.2
unnamed: A3.3 (1B), J12.1
unnamed: A3.5 (2A), J12.3
unnamed: A3.6 (2B), J12.4
unnamed: A3.13 (~RESET), A3.14 (~SLEEP)
unnamed: D2.2 (A), R1.2
VIN: J9.15, J14.1, J14.2

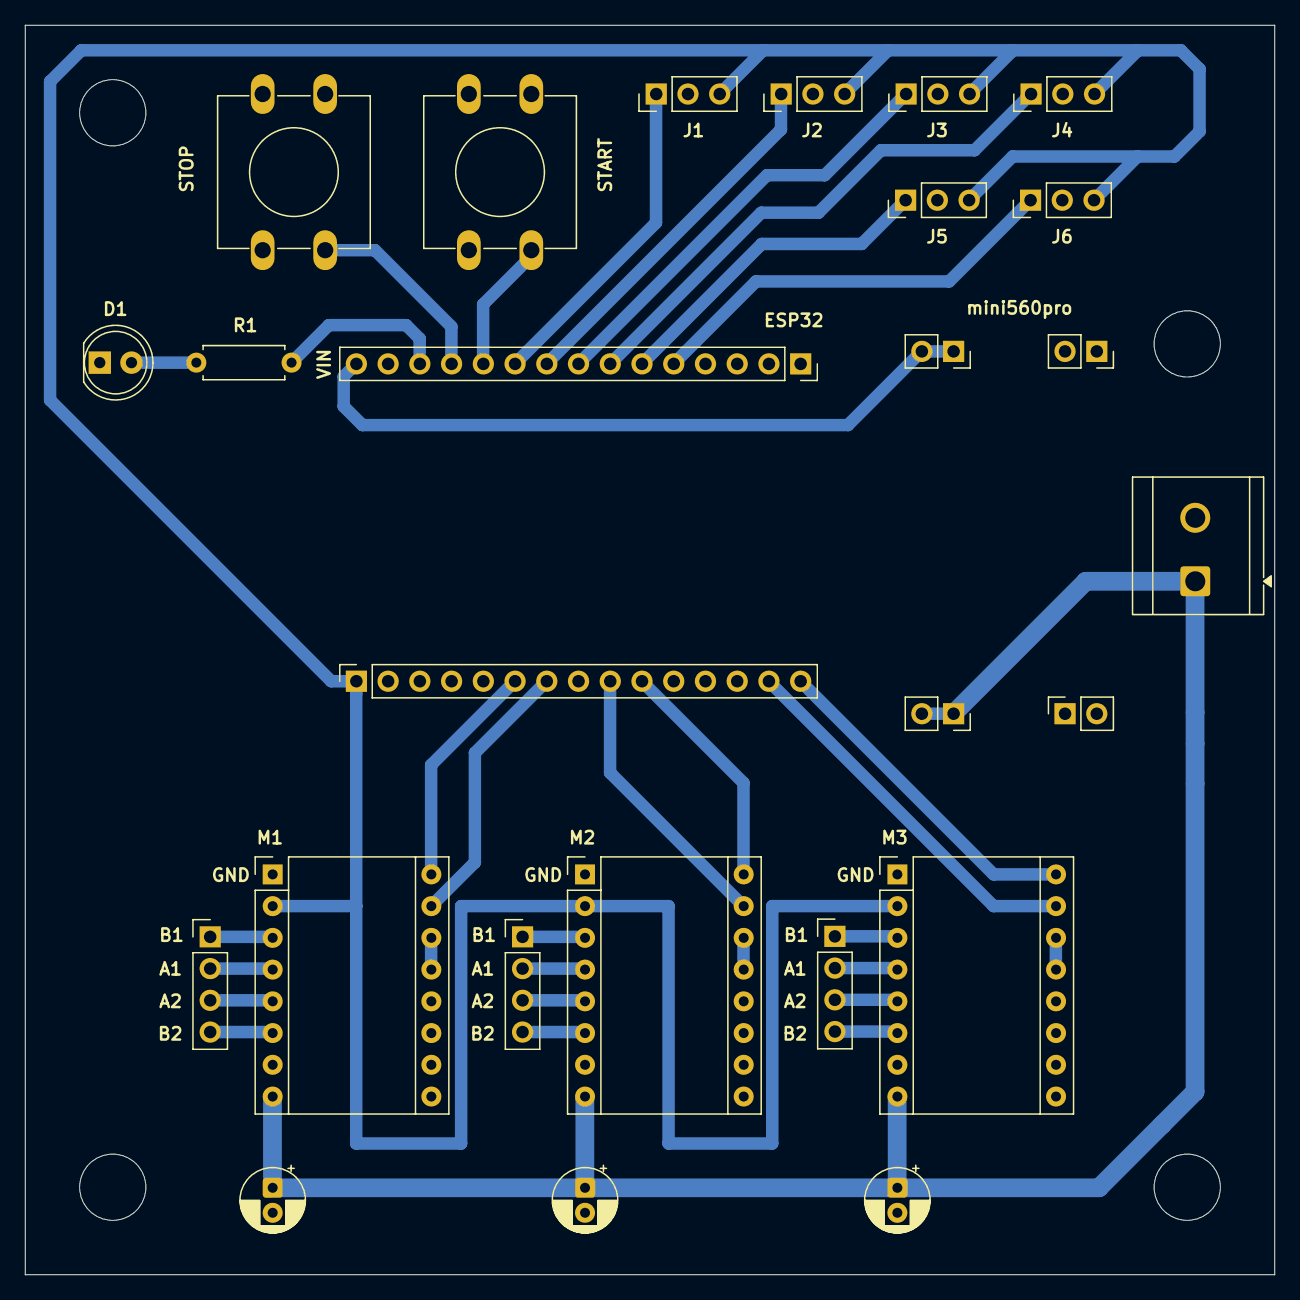
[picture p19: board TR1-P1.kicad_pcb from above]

Board: 2 copper layers, 100.0 x 100.0 mm, 26 parts (0 on the bottom side), 35 nets.

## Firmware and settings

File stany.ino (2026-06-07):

#include <AccelStepper.h>

// Define motor interface type
#define motorInterfaceType 1

#define dirPin1 23
#define dirPin2 19
#define dirPin3 16

#define stepPin1 22
#define stepPin2 18
#define stepPin3 17

#define kran_x 35
#define kran_y 32
#define kran_z_1 33
#define kran_z_2 25

#define STARTbutton 14
#define STOPbutton 12
#define LED 13

AccelStepper stepper1(motorInterfaceType, stepPin1, dirPin1);
AccelStepper stepper2(motorInterfaceType, stepPin2, dirPin2);
AccelStepper stepper3(motorInterfaceType, stepPin3, dirPin3);

enum State {
  STATE_IDLE,               // Await for first press of a START 
  STATE_ZERO,               // Zero position
  STATE_HOME,               // Go to the starting position
  STATE_WAIT,               // Await for the second press of a START
  STATE_START,              // Puts end-effector to working position
  STATE_MAIN_MOVEMENT       // Activate programmed trajectory (circle)
};

State currentState = STATE_IDLE;

bool is_X_true = false;
bool is_Y_true = false;
bool is_Z_true = false;


//Parametry opóźnienia DEL
unsigned long previousMillis_WAIT = 0;
const long interval_WAIT = 1000;
const long interval_BUTTON_PRESSED = 100;
int ledState = HIGH; 
// Parametry ruchu
int predkosc_x = 150;
int predkosc_y = 150;
int kroki_x = 100;
int kroki_y = 100;
// Czas pracy, 1 cykl koła ~ 4200 ms
// Ustawiamy długość procesu w min.
int minuty = 1;
int wymagana_liczba = round((minuty*60*1000)/4200);
const int n = 100; 
long cel_x[n];
long cel_y[n];

void setup() {
  // Inicjalizacja Monitora Szeregowego (standardowa prędkość dla ESP32)
  //Serial.begin(115200);
  
  // Konfiguracja krańcówek i przycisków jako wejścia z Pull-upem
  pinMode(kran_x, INPUT_PULLUP);
  pinMode(kran_y, INPUT_PULLUP);
  pinMode(kran_z_1, INPUT_PULLUP);
  pinMode(kran_z_2, INPUT_PULLUP);
  pinMode(STARTbutton, INPUT_PULLUP);
  pinMode(STOPbutton, INPUT_PULLUP);

  stepper1.setMaxSpeed(1000);
  stepper1.setAcceleration(240);
  stepper2.setMaxSpeed(1000);
  stepper2.setAcceleration(240);

  stepper3.setMaxSpeed(1000);
  stepper3.setAcceleration(120);
  stepper3.setMinPulseWidth(3);

  pinMode(LED, OUTPUT);

/* UNUSED, it is a first iteration of creating desired trajectory
  float resolution = (2.0*PI)/n; 
  int promien = kroki_x;
  for (int i = 0; i < n; i++){
  float kat = i * resolution; 
  cel_x[i] = round(promien * cos(kat));
  cel_y[i] = round(promien * sin(kat));
*/
}

  Serial.println("IDLE");
}

void loop() {
  unsigned long currentMillis_WAIT = millis();
  
  //UNUSED
  //int valueSTART = digitalRead(STARTbutton);
  //int valueSTOP = digitalRead(STOPbutton);
  
  int value_x = digitalRead(kran_x);
  int value_y = digitalRead(kran_y);
  int value_z_1 = digitalRead(kran_z_1); // DOLNA
  int value_z_2 = digitalRead(kran_z_2); // GÓRNA

  digitalWrite(LED, ledState);

  switch (currentState) {
    case STATE_IDLE:

      stepper1.setSpeed(0);
      stepper2.setSpeed(0);
      stepper3.setSpeed(0);
      ledState = HIGH;
      if (digitalRead(STARTbutton) == LOW) {

        for (int i = 0; i < 3; i++)
        {
          delay(interval_BUTTON_PRESSED);
          ledState = (ledState == LOW) ? HIGH : LOW;
          digitalWrite(LED, ledState);
        }
        //Serial.println("Initializing...\n");
        ledState = LOW;
        is_X_true = false;
        is_Y_true = false;
        is_Z_true = false;
        
        // Speed for zero-ing position
        stepper1.setSpeed(200);
        stepper2.setSpeed(200);
        stepper3.setSpeed(-30); 

        currentState = STATE_ZERO;
        delay(500);
      }
      break;
    

    case STATE_ZERO:

      if (digitalRead(STOPbutton) == LOW)
        currentState = STATE_IDLE;

      if (!is_X_true) {
        if (value_x == LOW) {
          //Serial.println("X is zero\n");
          stepper1.setCurrentPosition(0);
          is_X_true = true;
        } else {
          stepper1.runSpeed();
        }
      }

      if (!is_Y_true) {
        if (value_y == LOW) {
          //Serial.println("Y is zero\n");
          stepper2.setCurrentPosition(0);
          is_Y_true = true;
        } else if (is_X_true) {
          stepper2.runSpeed();
        }
      }

      if (!is_Z_true) {
        if (value_z_1 == LOW) {
          //Serial.println("Z is zero\n");
          stepper3.setCurrentPosition(0);
          is_Z_true = true;
        } else if (is_Y_true && is_X_true) {
          stepper3.runSpeed();
        }
      }

      if (is_X_true && is_Y_true && is_Z_true) {
        //Serial.println("State Zero has Finished...\n");
        stepper1.moveTo(-150);
        stepper2.moveTo(-200);
        stepper3.setSpeed(150);
        is_Z_true = false;
        currentState = STATE_HOME;
        delay(500);
      }
      break;
    

    case STATE_HOME:
      
      if (digitalRead(STOPbutton) == LOW)
        currentState = STATE_IDLE;

      stepper1.run();
      stepper2.run();
      
      if (value_z_2 == LOW) {
        is_Z_true = true;
      } else {
        stepper3.runSpeed();
      }

      if (stepper1.distanceToGo() == 0 && stepper2.distanceToGo() == 0 && is_Z_true) {
        //Serial.println("HOME reached...");
        
        stepper1.setCurrentPosition(0);
        stepper2.setCurrentPosition(0);
        stepper3.setCurrentPosition(0);

        stepper1.setSpeed(predkosc_x);
        stepper2.setSpeed(predkosc_y);
        stepper3.setSpeed(-200);

        currentState = STATE_WAIT;
      }
      break;
    

    //TODO LED CONTROL
    case STATE_WAIT:
      
      if (digitalRead(STOPbutton) == LOW)
        currentState = STATE_IDLE;

      if (digitalRead(STARTbutton) == LOW) {
        for (int i = 0; i < 3; i++)
        {
          delay(interval_BUTTON_PRESSED);
          ledState = (ledState == LOW) ? HIGH : LOW;
          digitalWrite(LED, ledState);
          }
          currentState = STATE_START; 
          delay(1000);
        }
        
      if (currentMillis_WAIT - previousMillis_WAIT >= interval_WAIT) {
        previousMillis_WAIT = currentMillis_WAIT; // Save the last toggle time

        // Toggle LED state
        ledState = (ledState == LOW) ? HIGH : LOW;
      }
      break;
    

    case STATE_START:
      if (digitalRead(STOPbutton) == LOW)
        currentState = STATE_IDLE;

      if (value_z_1 == LOW)
        currentState = STATE_MAIN_MOVEMENT;
      else
        stepper3.runSpeed();
      break;
    

    case STATE_MAIN_MOVEMENT: {
      
      if (digitalRead(STOPbutton) == LOW)
        currentState = STATE_IDLE;

      ledState = LOW;
      digitalWrite(LED, ledState);
      while(digitalRead(kran_x) == HIGH && currentState == STATE_MAIN_MOVEMENT){
        if (digitalRead(STOPbutton) == LOW)
        currentState = STATE_IDLE;

        stepper1.runSpeed();
        }
      
      stepper1.setCurrentPosition(0);
      stepper1.moveTo(-10);
      
      while (stepper1.distanceToGo() != 0 && currentState == STATE_MAIN_MOVEMENT){
        if (digitalRead(STOPbutton) == LOW)
        currentState = STATE_IDLE;

        stepper1.run();
        }
      
      stepper1.setCurrentPosition(0);

      float obwod_kroki = 2.0 * PI * kroki_x;
      unsigned long czas_okregu_ms = (obwod_kroki / predkosc_x) * 1000;

      float max_v_x = predkosc_x;
      float max_v_y = predkosc_y;

      for (int cykl = 0; cykl < wymagana_liczba; cykl++) {
        if (currentState != STATE_MAIN_MOVEMENT) break;
        if (digitalRead(STOPbutton) == LOW)
          currentState = STATE_IDLE;
       
        unsigned long start_cyklu = millis();
        unsigned long czas_aktualny = millis();

        while (czas_aktualny - start_cyklu < czas_okregu_ms && currentState == STATE_MAIN_MOVEMENT) {
          
          if (digitalRead(STOPbutton) == LOW)
            currentState = STATE_IDLE;

          czas_aktualny = millis();
          float progres = (float)(czas_aktualny - start_cyklu) / czas_okregu_ms;
          float kat = progres * 2.0 * PI;
          float aktualna_predkosc_x = -max_v_x * sin(kat);
          float aktualna_predkosc_y = max_v_y * cos(kat);

          stepper1.setSpeed(aktualna_predkosc_x);
          stepper2.setSpeed(aktualna_predkosc_y);
          stepper1.runSpeed();
          stepper2.runSpeed();
          yield();
        }
      }

      stepper1.setSpeed(0);
      stepper2.setSpeed(0);

      stepper3.setSpeed(200); 
      while (digitalRead(kran_z_2) == HIGH && currentState == STATE_MAIN_MOVEMENT) {
        stepper3.runSpeed();
        yield();
      }
      
      currentState = STATE_IDLE;
      ledState = HIGH;
      break;
    }
  }
}

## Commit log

2026-06-07 Base code for the robot
    Code that makes robot move the end-effector by the desired trajectory (which currently is circle), whole structure is based on the state-machine for ESP32, written in the Arduino IDE
2026-06-07 Enhance README with system architecture and pin mapping
    Added detailed descriptions of the system's components, pin mapping, and state machine architecture.
2026-06-07 Update pin mapping for ESP32 in README.md
